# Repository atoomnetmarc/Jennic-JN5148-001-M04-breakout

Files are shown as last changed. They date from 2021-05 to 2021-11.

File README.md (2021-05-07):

Yes, the JN5148-001-M04 module is old. NXP has professionally erased all documents and software from their website except for the [product brief](https://www.nxp.com/products/no-longer-manufactured/32-bit-mcu-and-ieee802-15-4-transceiver:JN5148).

However, I have some JN5148-001-M04 modules and want to play with them. So I created this crude breakout board.

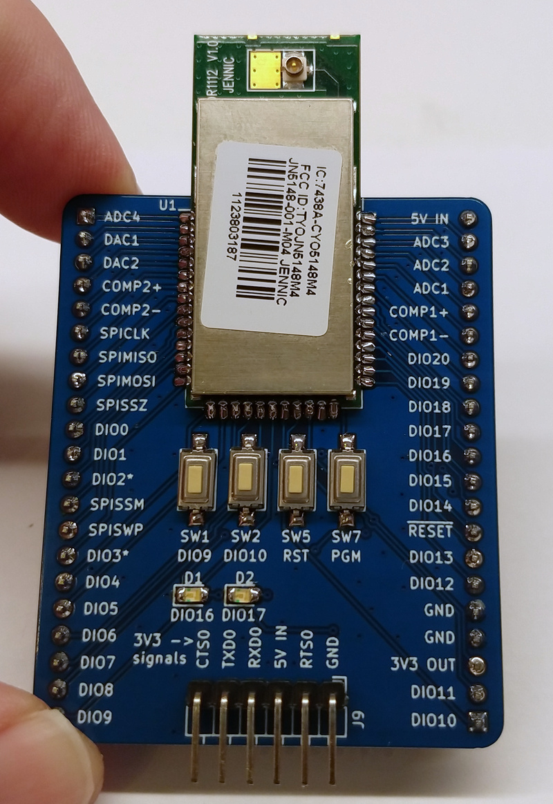
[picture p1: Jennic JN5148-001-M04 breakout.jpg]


# Assembly instructions

Solder all components except the module. Clean PCB.

Test if 3V3 regulator works by connecting 5V (with 50mA power limit). The board should not use any significant current. Measure the 3V3 OUT-pin, it should be 3.3V.

Now solder module.

# Test programming mode

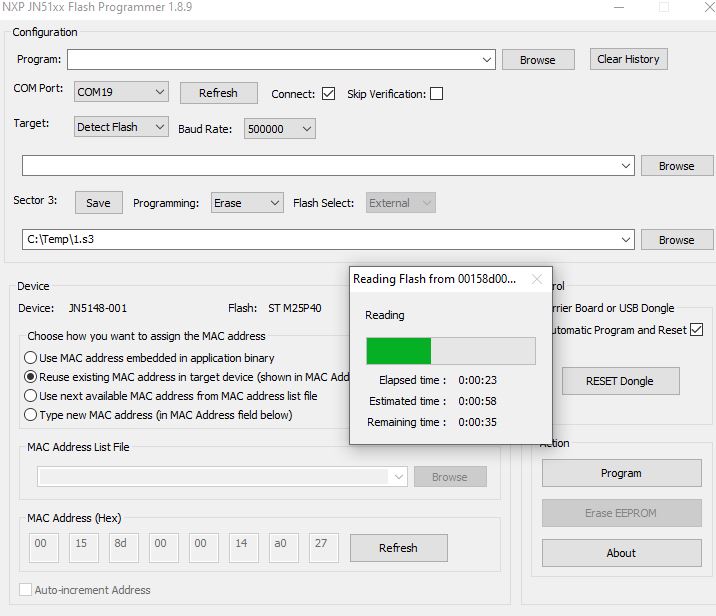
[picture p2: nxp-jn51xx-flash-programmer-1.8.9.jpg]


Use 'NXP JN51xx Flash Programmer 1.8.9'. Connect a 3.3V serial to USB converter (like a FT232RL) and put Jennic module into program mode by pressing and holding PGM while short pressing RST.\
When selecting a COM Port the programming software should identify the device type, flash chip and MAC Address.



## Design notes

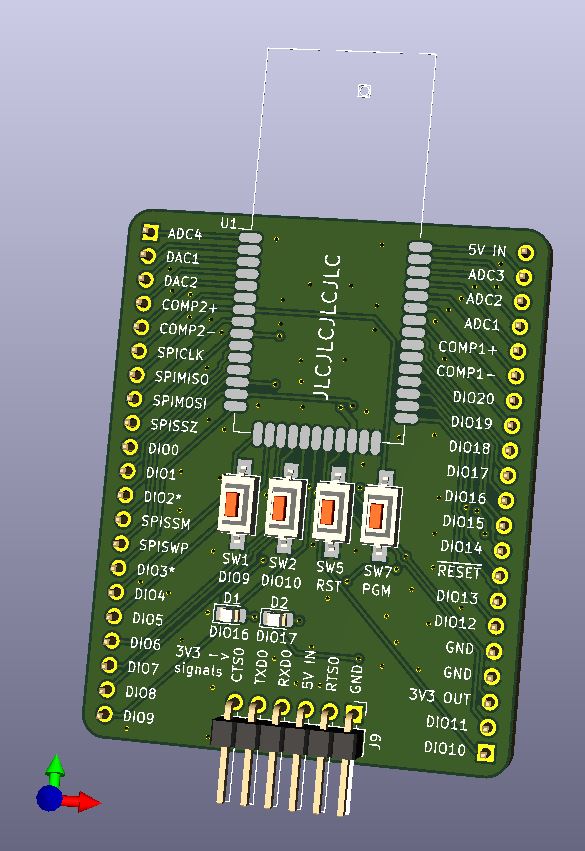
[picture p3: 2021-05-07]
Jennic JN5148-001-M04 breakout-render.jpg

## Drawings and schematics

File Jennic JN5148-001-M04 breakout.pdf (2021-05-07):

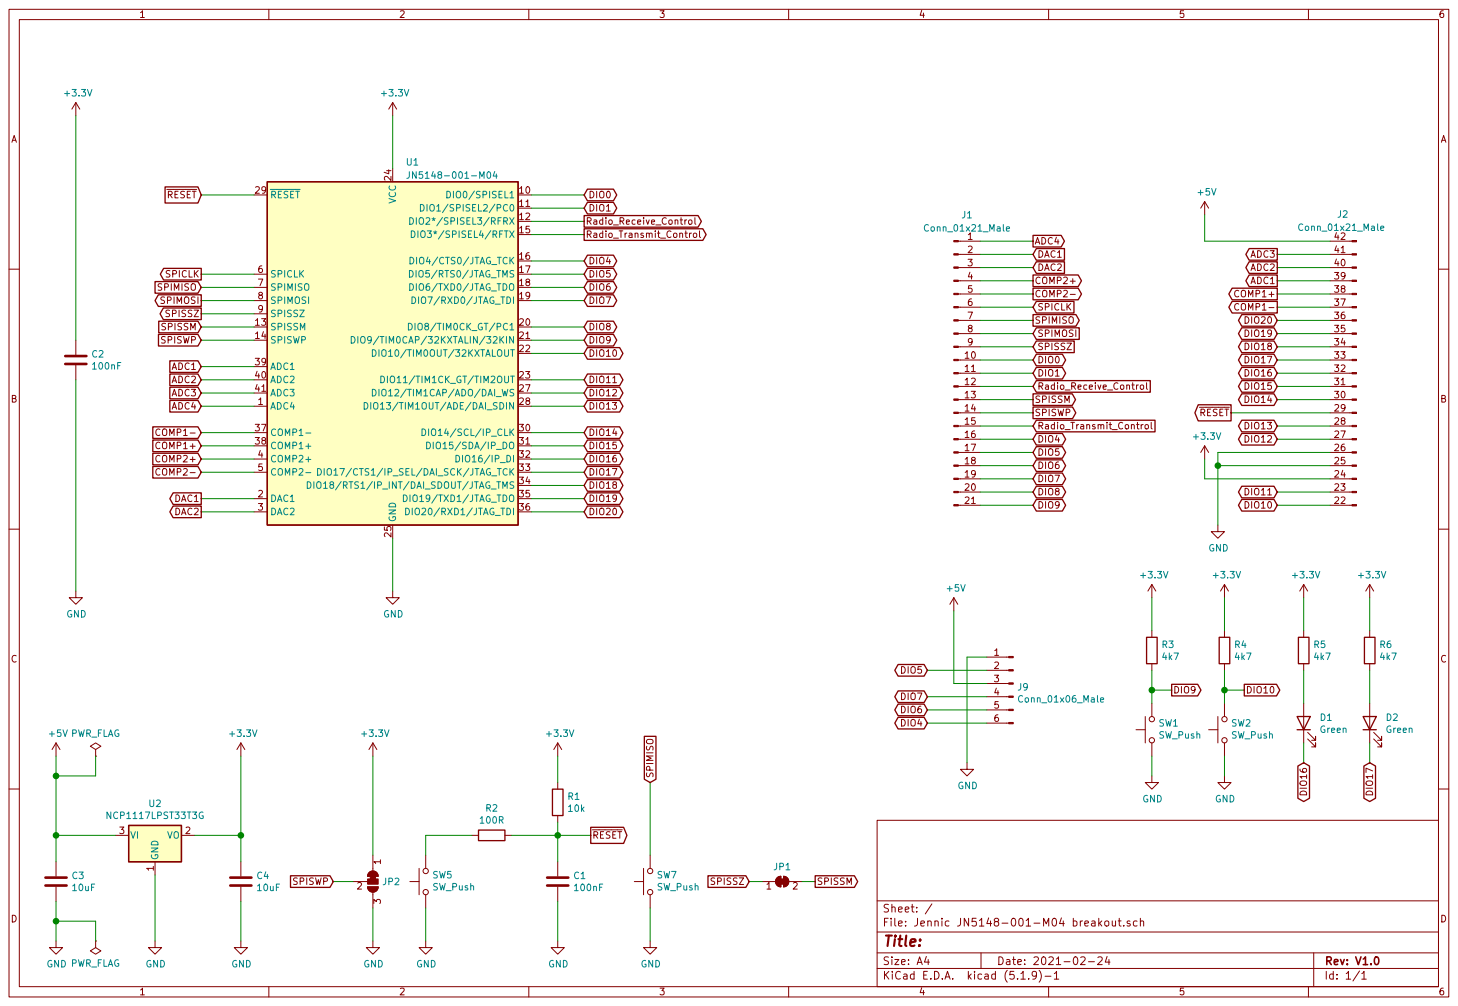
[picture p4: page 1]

Id: 1/1 Title: File: Jennic JN5148-001-M04 breakout.sch Sheet: / GND

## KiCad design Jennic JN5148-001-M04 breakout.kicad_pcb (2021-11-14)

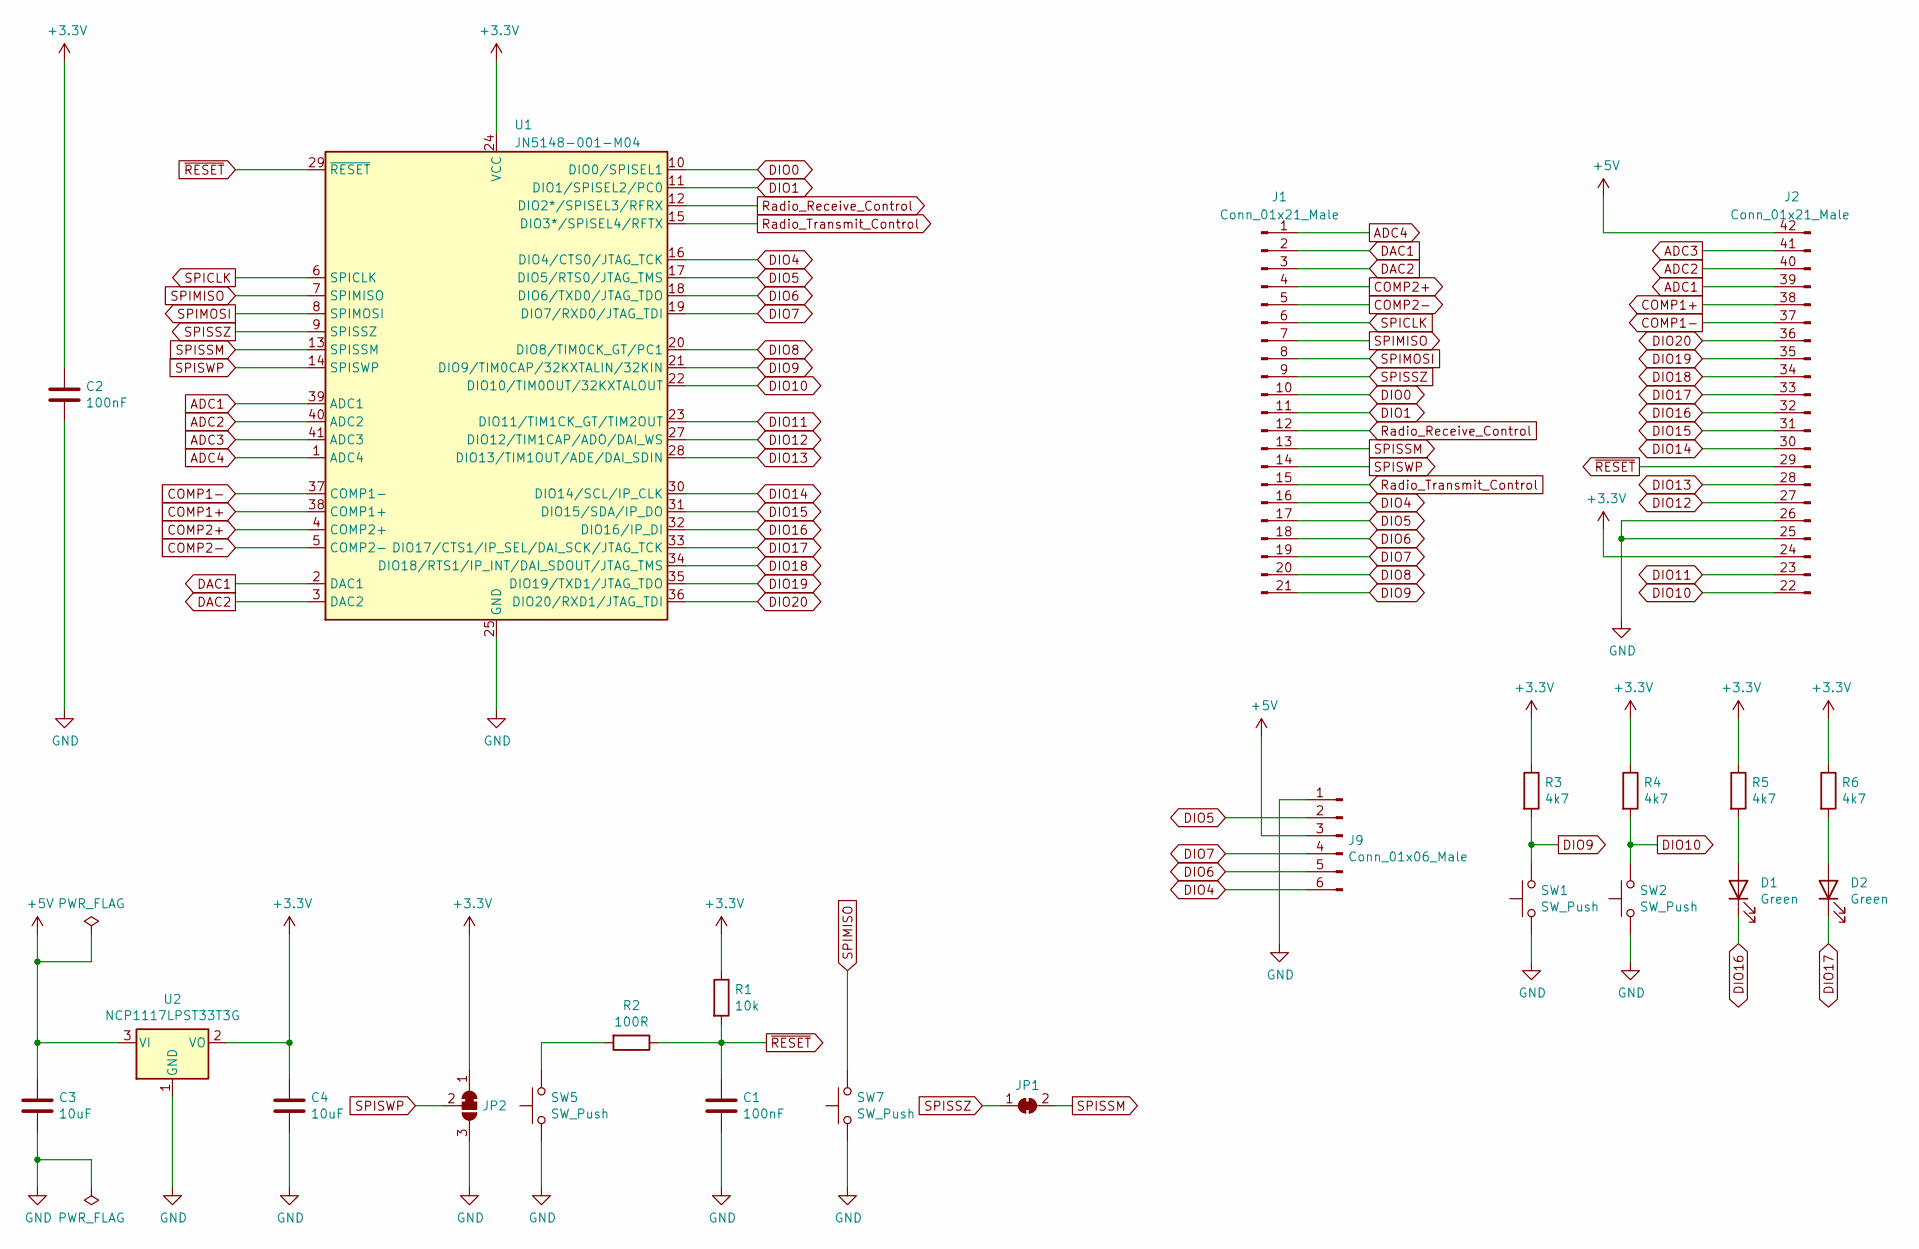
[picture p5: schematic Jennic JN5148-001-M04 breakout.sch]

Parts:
C1, C2: 100nF; C_0805_2012Metric_Pad1.18x1.45mm_HandSolder
C3, C4: 10uF; C_0805_2012Metric_Pad1.18x1.45mm_HandSolder
D1, D2: Green; LED_0805_2012Metric_Pad1.15x1.40mm_HandSolder
J1: Conn_01x21_Male; PinHeader_1x21_P2.54mm_Vertical
J2: Conn_01x21_Male; PinHeader_1x21+21_P2.54mm_Vertical
J9: Conn_01x06_Male; PinHeader_1x06_P2.54mm_Horizontal
JP1: SolderJumper_2_Bridged; SolderJumper-2_P1.3mm_Bridged_RoundedPad1.0x1.5mm
JP2: SolderJumper_3_Bridged12; SolderJumper-3_P1.3mm_Bridged12_RoundedPad1.0x1.5mm
R1: 10k; R_0805_2012Metric_Pad1.20x1.40mm_HandSolder
R2: 100R; R_0805_2012Metric_Pad1.20x1.40mm_HandSolder
R3, R4, R5, R6: 4k7; R_0805_2012Metric_Pad1.20x1.40mm_HandSolder
SW1, SW2, SW5, SW7: SW_Push; SW_SPST_CK_RS282G05A3
U1: JN5148-001-M04; JN5148-001-M04-handsolder
U2: NCP1117LPST33T3G; SOT-223-3_TabPin2

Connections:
+3V3: C2.1, C4.1, J2.24 (Pin_3), JP2.1 (A), R1.1, R3.1, R4.1, R5.1, R6.1, U1.24 (VCC), U2.2 (VO)
+5V: C3.1, J2.42 (Pin_21), J9.3, U2.3 (VI)
ADC1: J2.39 (Pin_18), U1.39 (ADC1)
ADC2: J2.40 (Pin_19), U1.40 (ADC2)
ADC3: J2.41 (Pin_20), U1.41 (ADC3)
ADC4: J1.1, U1.1 (ADC4)
COMP1+: J2.38 (Pin_17), U1.38 (COMP1+)
COMP1-: J2.37 (Pin_16), U1.37 (COMP1-)
COMP2+: J1.4, U1.4 (COMP2+)
COMP2-: J1.5, U1.5 (COMP2-)
DAC1: J1.2, U1.2 (DAC1)
DAC2: J1.3, U1.3 (DAC2)
DIO0: J1.10, U1.10 (DIO0/SPISEL1)
DIO1: J1.11, U1.11 (DIO1/SPISEL2/PC0)
DIO4: J1.16, J9.6, U1.16 (DIO4/CTS0/JTAG_TCK)
DIO5: J1.17, J9.2, U1.17 (DIO5/RTS0/JTAG_TMS)
DIO6: J1.18, J9.5, U1.18 (DIO6/TXD0/JTAG_TDO)
DIO7: J1.19, J9.4, U1.19 (DIO7/RXD0/JTAG_TDI)
DIO8: J1.20, U1.20 (DIO8/TIM0CK_GT/PC1)
DIO9: J1.21, R3.2, SW1.2, U1.21 (DIO9/TIM0CAP/32KXTALIN/32KIN)
DIO10: J2.22 (Pin_1), R4.2, SW2.2, U1.22 (DIO10/TIM0OUT/32KXTALOUT)
DIO11: J2.23 (Pin_2), U1.23 (DIO11/TIM1CK_GT/TIM2OUT)
DIO12: J2.27 (Pin_6), U1.27 (DIO12/TIM1CAP/ADO/DAI_WS)
DIO13: J2.28 (Pin_7), U1.28 (DIO13/TIM1OUT/ADE/DAI_SDIN)
DIO14: J2.30 (Pin_9), U1.30 (DIO14/SCL/IP_CLK)
DIO15: J2.31 (Pin_10), U1.31 (DIO15/SDA/IP_DO)
DIO16: D1.1 (K), J2.32 (Pin_11), U1.32 (DIO16/IP_DI)
DIO17: D2.1 (K), J2.33 (Pin_12), U1.33 (DIO17/CTS1/IP_SEL/DAI_SCK/JTAG_TCK)
DIO18: J2.34 (Pin_13), U1.34 (DIO18/RTS1/IP_INT/DAI_SDOUT/JTAG_TMS)
DIO19: J2.35 (Pin_14), U1.35 (DIO19/TXD1/JTAG_TDO)
DIO20: J2.36 (Pin_15), U1.36 (DIO20/RXD1/JTAG_TDI)
GND: C1.2, C2.2, C3.2, C4.2, J2.25 (Pin_4), J2.26 (Pin_5), J9.1, JP2.3 (B), SW1.1, SW2.1, SW5.1, SW7.1, U1.25 (GND), U1.26 (GNDA), U2.1 (GND)
unnamed: D1.2 (A), R5.2
unnamed: D2.2 (A), R6.2
unnamed: R2.2, SW5.2
Radio_Receive_Control: J1.12, U1.12 (DIO2*/SPISEL3/RFRX)
Radio_Transmit_Control: J1.15, U1.15 (DIO3*/SPISEL4/RFTX)
SPICLK: J1.6, U1.6 (SPICLK)
SPIMISO: J1.7, SW7.2, U1.7 (SPIMISO)
SPIMOSI: J1.8, U1.8 (SPIMOSI)
SPISSM: J1.13, JP1.2 (B), U1.13 (SPISSM)
SPISSZ: J1.9, JP1.1 (A), U1.9 (SPISSZ)
SPISWP: J1.14, JP2.2 (C), U1.14 (SPISWP)
~RESET: C1.1, J2.29 (Pin_8), R1.2, R2.1, U1.29 (~RESET)

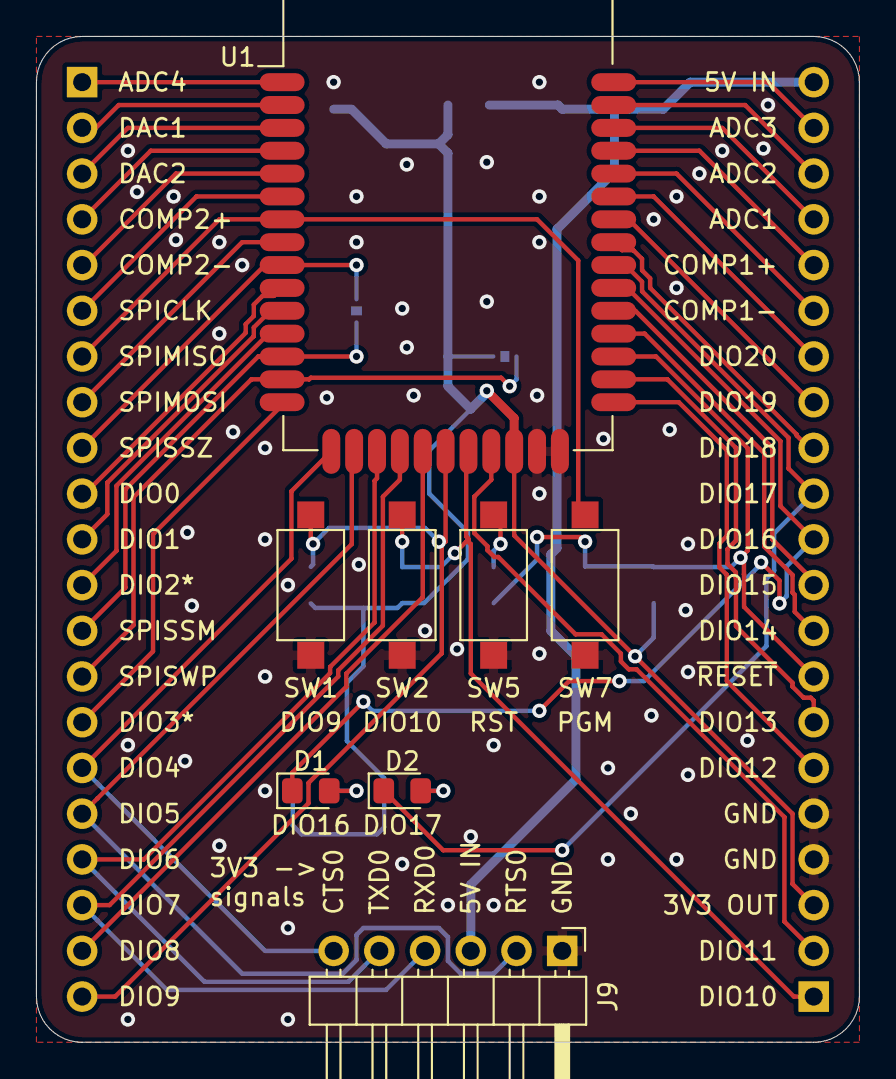
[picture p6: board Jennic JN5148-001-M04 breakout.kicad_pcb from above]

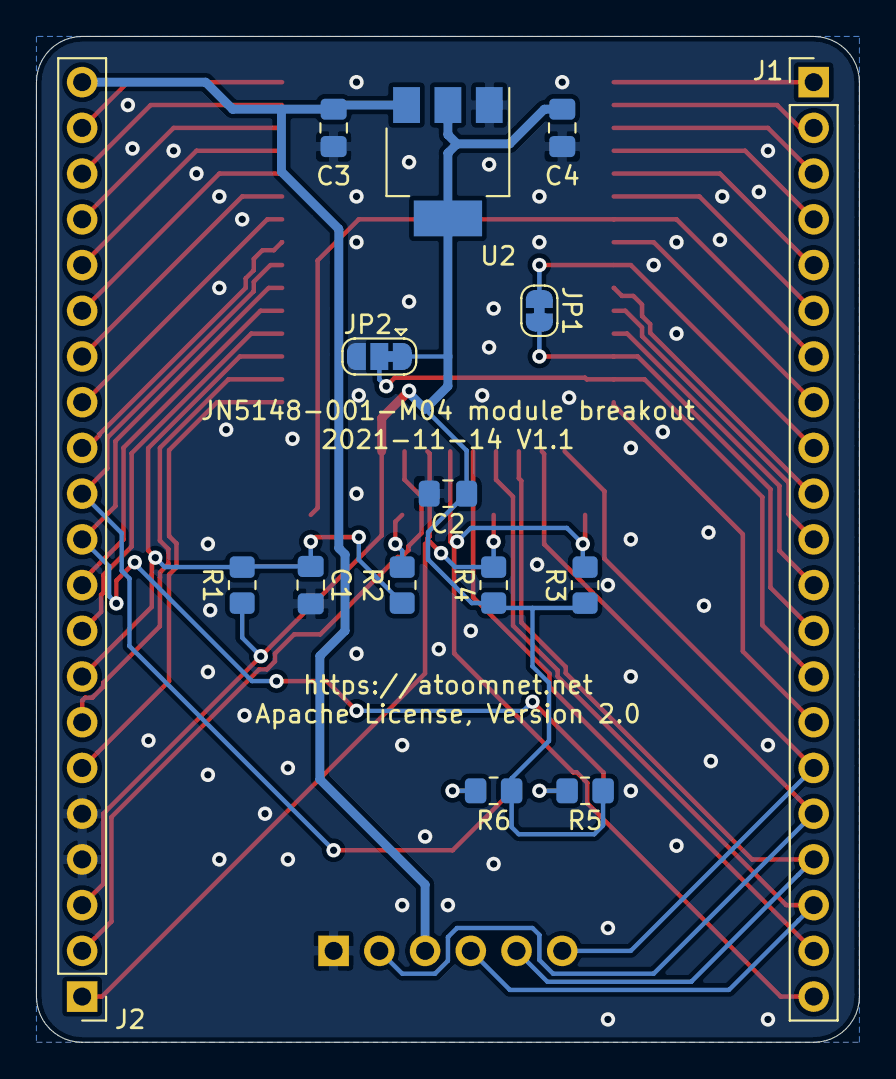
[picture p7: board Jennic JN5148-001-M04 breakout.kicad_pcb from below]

Board: 2 copper layers, 45.7 x 55.9 mm, 23 parts (15 on the bottom side), 44 nets.

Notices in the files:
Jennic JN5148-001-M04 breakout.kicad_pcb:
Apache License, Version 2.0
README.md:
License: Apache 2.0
